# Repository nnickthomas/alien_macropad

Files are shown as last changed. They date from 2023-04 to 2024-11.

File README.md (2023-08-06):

# 👽Alien Macropad

A DIY standalone macropad using the Raspberry Pi Pico W for homeassistant, twitch, or anything.

  

👽 🐄 🛸 ⭐ 🌙 🪐 🌌

them big green aliens they came them gone they took my cows

## Features 🐄

- Designed for the Pi Pico W
- Standalone device, not a keypad
- Open Source PCB designs (all files required to print your own PCB)
- Fits cherry-style switches (either plate or pcb mount)

## GPIO Pinout Map 🛸

The following pins on the Pi's GPIO pinouts correspond to the following switches:

| Switch  | GPIO Pin |
| --- | --- |
| SW1  | GP5 |
| SW2  | GP6  |
| SW3  | GP4  |
| SW4  | GP7  |
| SW5  | GP3  |
| SW6  | GP8 |

Please note that odd numbered switches (SW1, SW3, SW5) share a common ground and even numbered switches (SW2, SW4, SW6) share a common ground.
## Assembly ⭐

The alien macropad requires the following components:

| Component  | Amount |
| --- | --- |
| Cherry Style Switches | 6x |
| Raspberry Pi Pico W  | 1x  |
| Alien Macropad PCB  | 1x  |
| Top Sandwich Plate  | 1x  |
| Surrounding Case  | 1x |
| Adhesive Rubber Feet  | 4x |

The following steps detail how to assemble the device:

1) Place the PI into the U1 slot on the PCB and solder into place from the top. Please note that it may be easier for some people to perform the installation step at this phase as the Boostel button will be partially covered by the top sandwich!
2) Place the Top Sandwich Plate on top
3) Insert switches SW1-SW6 into the slots and solder into place from the bottom.
4) Place inside the Surrounding Case! (Alternatively use the Bottom Sandwich Plate for a lower profile look)
5) Proceed to Installation!

## Installation 🌙

This section will detail how to install the Alien Macropad software onto the now connected Pi Pico W. Please note this has not yet been tested! Also see the official [Raspberry Pi Documentation](https://projects.raspberrypi.org/en/projects/get-started-pico-w/)

   1) Download the latest version of the alien macropad. There will be two files inside (main.py and conf.json)
   2) Set your wi-fi credentials in conf.json. Create your actions in conf.json (see the [firmware documentation](https://github.com/nnickthomas/alien_macropad/tree/main/Firmware).
   3) Connect the microUSB cable to the Pi Pico W.
   4) While holding down the "Boostel" button on the PICO, connect the device to another computer.
   5) Copy the main.py file, and your modified conf.json onto the pi into the now opened directory. The file manager will open automatically on Windows and the files can be dragged over.
   6) Download the correct [firmware](https://rpf.io/pico-w-firmware) for the Pi Pico W. The regular Pi Pico has not been tested.
   7) Copy the firmware file above onto the opened directory.

    **_NOTE:_**  It is critical to add main.py and conf.json before the pico firmware!
    
## Configuration 🪐

The Alien Macropad uses a JSON file to configure functionality. The JSON file is also where the wi-fi credentials are set.

For instructions on how to configure the device, see the [firmware]((https://github.com/nnickthomas/alien_macropad/tree/main/Firmware)) section.

## Project Structure 🌌

    alien_macropad/
    ├── Case
    │   ├── PCB_Model.obj
    │   ├── alien_macro_lower_sandwich.stl
    │   └── alien_macro_top_sandwich.stl
    ├── Firmware
    │   ├── .picowgo
    │   ├── README.md
    │   ├── conf.json
    │   └── main.py
    ├── Gerber Files
    │   ├── Macropad-B_Cu.gbr
    │   ├── Macropad-B_Mask.gbr
    │   ├── Macropad-B_Paste.gbr
    │   ├── Macropad-Edge_Cuts.gbr
    │   ├── Macropad-F_Cu.gbr
    │   ├── Macropad-F_Mask.gbr
    │   ├── Macropad-F_Paste.gbr
    │   ├── Macropad-F_Silkscreen.gbr
    │   ├── Macropad-NPTH-drl_map.gbr
    │   ├── Macropad-NPTH.drl
    │   ├── Macropad-PTH-drl_map.gbr
    │   ├── Macropad-PTH.drl
    │   └── Macropad-job.gbrjob
    ├── .gitignore
    ├── LICENSE
    └── README.md

The main directory contains the following files and directories:

 - Case/: A directory containing the STL files for 3D printing the case.
 - Firmware/: A directory containing the firmware files for the Alien Macropad.
 - Gerber Files/: A directory containing the Gerber files for manufacturing the PCB.
 - .gitignore: The Git ignore file for the project.
 - LICENSE: The license file for the project.
 - README.md: The project's main README file.

The Case/ directory contains the following files:

 - PCB_Model.obj: An OBJ file with the PCB size for reference. Not used in assembly.
 - alien_macro_lower_sandwich.stl: An STL file for 3D printing the bottom part of the case.
 - alien_macro_top_sandwich.stl: An STL file for 3D printing the top part of the case.

The Firmware/ directory contains the following files:

 - .picowgo: This file is just used to identify a project folder.
 - README.md: A README file for the Firmware/ directory.
 - conf.json: A configuration file for the Alien Macropad.
 - main.py: The main firmware code for the Alien Macropad.

The Gerber Files/ directory contains the following files:

 - Macropad-B_Cu.gbr: The bottom copper layer of the PCB.
 - Macropad-B_Mask.gbr: The bottom solder mask layer of the PCB.
 - Macropad-B_Paste.gbr: The bottom paste layer of the PCB.
 - Macropad-Edge_Cuts.gbr: The edge cut layer of the PCB.
 - Macropad-F_Cu.gbr: The top copper layer of the PCB.
 - Macropad-F_Mask.gbr: The top solder mask layer of the PCB.
 - Macropad-F_Paste.gbr: The top paste layer of the PCB.
 - Macropad-F_Silkscreen.gbr: The top silkscreen layer of the PCB.
 - Macropad-NPTH.drl: The non-plated through holes drill file.
 - Macropad-PTH.drl: The plated through holes drill file.
 - Macropad-job.gbrjob: The job file for manufacturing the PCB.

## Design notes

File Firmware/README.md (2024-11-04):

# 👽 Alien Macropad Firmware

This directory contains the firmware for the Alien Macropad. The firmware is written in Circuitpython and is designed to run on the Pico microcontroller.

## GPIO Pinout Map 🛸

The following pins on the Pi's GPIO pinouts correspond to the following switches:

| Switch  | GPIO Pin |
| --- | --- |
| SW1  | GP5 |
| SW2  | GP6  |
| SW3  | GP4  |
| SW4  | GP7  |
| SW5  | GP3  |
| SW6  | GP8 |

Please note that odd numbered switches (SW1, SW3, SW5) share a common ground and even numbered switches (SW2, SW4, SW6) share a common ground.

## First Time Setup

To get started with the Alien Macropad, follow these steps:

1. Install the latest version of CircuitPython on the Pico. You can download the latest version of CircuitPython from the [CircuitPython website](https://circuitpython.org/board/raspberry_pi_pico_w/). (Note: The Alien Macropad firmware was developed using CircuitPython 9.0.4.)

2. Copy the contents of this directory to the Pico. You can do this by copying the contents of the `Firmware` directory to the `CIRCUITPY` drive on the Pico.

3. Once the files have been copied, reboot the Pico and hold down `SW1`. The Alien Macropad will boot into setup mode and create a Wi-Fi access point called `AlienPad`. Connect to this access point using your computer or mobile device.

4. Once connected to the `AlienPad` access point, open a web browser and navigate to `http://192.168.4.1`. You will be prompted to select the SSID and enter the password for your Wi-Fi network. Enter the SSID and password and click `Connect`.

5. (Optional) If you want to configure an MDNS name for the Alien Macropad, you can do so by entering the desired name in the `MDNS Name` field before clicking `Connect`.

6. Once you have connected to your Wi-Fi network, the Alien Macropad will reboot and connect to the network. You can now access the Alien Macropad by navigating to `http://<mdns_name>.local` or `http://<ip_address>` in your web browser. The default MDNS name is `alienpad.local`.

## ☄️ Configuration

The Alien Macropad buttons are configured via the web interface. Unless you have deviated from the provided gerber files, the default layout in the web interface should match the physical layout of the Alien Macropad.

### 🚀 Buttons

Each key can be configured to action something different. This supports multiple actions per key, and toggling funtionality.

The Alien Macropad firmware supports all types of HTTP requests:

For both types of requests, the following parameters can be configured:

 - url: The URL to send the request to
 - json: A JSON payload to include in the request
 - headers: A dictionary of headers to include in the request
 - data: The data to include in the request body

### 🌟 Sequence Mode

In sequence mode, each button press sends a sequence of requests to the configured URLs, in the order the requests are defined. Once all requests in the sequence have been sent, the button will no longer send any requests until it is pressed again.

To use sequence mode, set the "mode" value to "sequence", then add your requests underneath it.

### 🌓 Cycle Mode

In cycle mode, each button press sends a single request defined in under 'request' one at a time, waiting for a new button press before sending the next. Once it reaches the end it will loop back to the beginning.

To use cycle mode, set the "mode" value to "cycle", then add your requests underneath it.

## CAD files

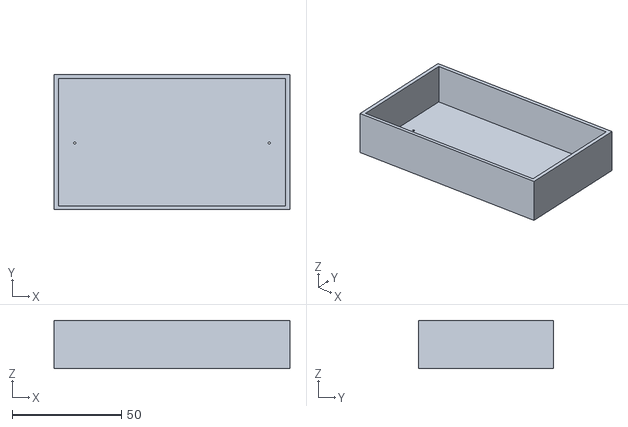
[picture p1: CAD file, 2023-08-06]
Case/alien_macro_surrounding_case.stl
108.0 x 62.0 x 22.0

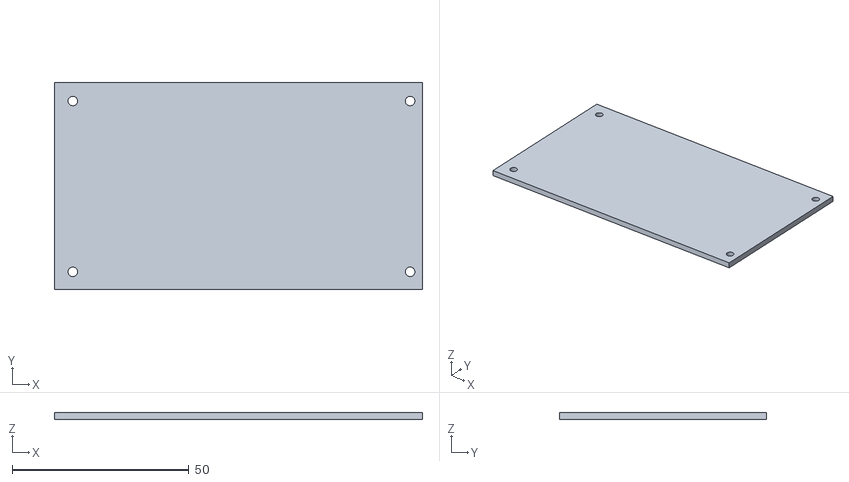
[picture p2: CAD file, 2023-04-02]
Case/alien_macro_lower_sandwich.stl
104.0 x 58.5 x 2.00

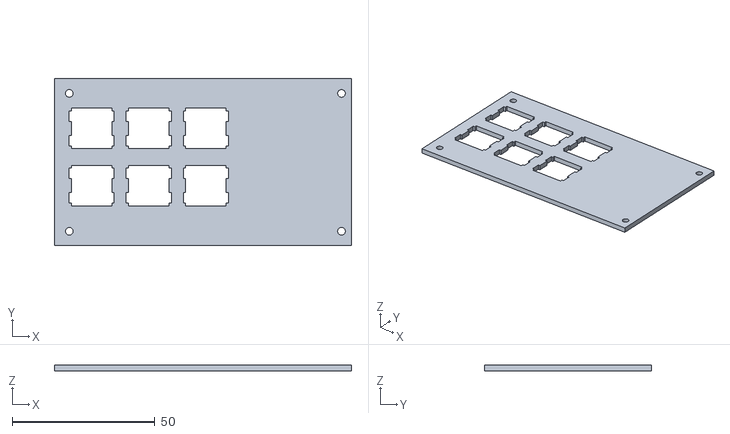
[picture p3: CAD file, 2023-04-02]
Case/alien_macro_top_sandwich.stl
104.0 x 58.5 x 2.00

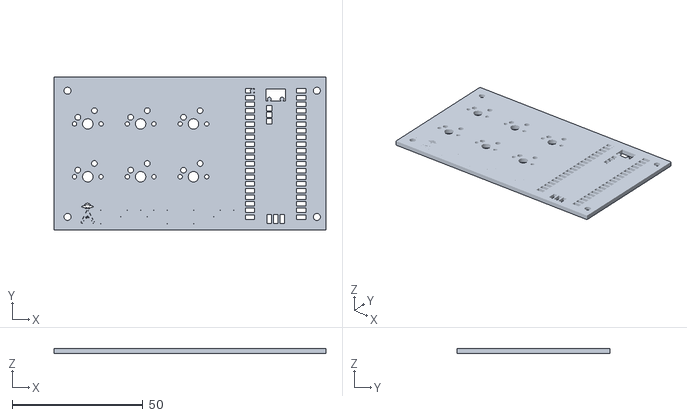
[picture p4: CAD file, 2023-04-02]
Case/PCB_Model.obj
104.0 x 58.5 x 2.00

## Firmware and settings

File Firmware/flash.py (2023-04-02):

import time
import json
import network
import uasyncio
import urequests

from machine import Pin

# Get configuration
with open("/conf.json") as fil:
    CONFIG = json.load(fil)

# On-board LED
LED = Pin("LED", Pin.OUT)

#------------------------------------------------
#                Task Functions
#------------------------------------------------
def blink_led(amt: int, speed: float) -> None:
    """Blinks the on-board LED

    Args:
        amt (int): Amount of times to blink the LED
        speed (float): Time in seconds to wait between blinks
    """
    for _ in range(amt * 2):
        LED.toggle()
        time.sleep(speed)


def connect_to_network(timeout: int = 10) -> bool:
    """Connect to the network defined in conf.py

    Args:
        timeout (int, optional): Amount of time in seconds to wait to connect. Defaults to 10.
    """
    wlan = network.WLAN(network.STA_IF)
    wlan.active(True)
    wlan.connect(CONFIG["network"]["ssid"], CONFIG["network"]["password"])

    # Wait for `timeout` seconds
    while timeout > 0:
        # If successful, blink the LED three times quickly and return True
        if wlan.status() < 0 or wlan.status() >= 3:
            blink_led(3, 0.1)
            LED.off()
            return True
        timeout -= 1
        blink_led(1, 1)

    # Deactivate network adapter and return False if failure to connect
    wlan.active(False)
    return False


#------------------------------------------------
#                Button Functions
#------------------------------------------------
async def switch_listener(button: dict, lock: uasyncio.Lock):
    """Asyncio function for listening to switch presses

    Args:
        button (dict): Button dict containing important information
        lock (uasyncio.Lock): Lock to ensure only one switch is pressed at a time
    """
    is_pressed = False
    switch = Pin(button["gpio"], Pin.IN, pull=Pin.PULL_UP)

    while True:
        # Handle button press
        if switch.value() == 0 and not is_pressed and not lock.locked():
            await lock.acquire()
            is_pressed = True

            res = urequests.request(**button["request"])

            if res:
                res.close()
            uasyncio.sleep_ms(200)

        # Release lock and set is_pressed to False
        if is_pressed and switch.value():
            is_pressed = False
            lock.release()

        await uasyncio.sleep_ms(5)


async def run_switch_listeners():
    """Main function to drive the Pico"""
    lock = uasyncio.Lock()
    for button in CONFIG["buttons"]:
        uasyncio.create_task(switch_listener(button, lock))


#------------------------------------------------
#                Main Function
#------------------------------------------------
def main():
    """Main Function"""
    if not connect_to_network():
        # If the board failed to connect to the network, blink a lot
        while True:
            blink_led(1, 0.1)
    
    uasyncio.run(run_switch_listeners())

    loop = uasyncio.get_event_loop()
    loop.run_forever()


if __name__ == "__main__":
    main()

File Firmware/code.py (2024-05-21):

import os
import json
import supervisor

from setup import setup_mode
from handler import running_mode

supervisor.set_next_code_file(filename = 'code.py', reload_on_error = False, reload_on_success = False)
supervisor.runtime.autoreload = False

if __name__ == '__main__':
    if os.getenv('MODE') == 'setup':
        setup_mode()
    else:
        try:
            with open('/wifi.json') as fil:
                wifi_config = json.load(fil)
                running_mode(**wifi_config)
        except Exception as e:
            setup_mode()

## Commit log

2023-04-02 Initial commit with hardware relevant files
    This includes the gerber files and the super simple sandwich case for the alien macropad.
    [Macropad-B_Cu.gbr, Macropad-B_Mask.gbr, Macropad-B_Paste.gbr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]
2023-04-02 Changed switch to button
2023-04-02 Added button types sequence and cycle
2023-08-06 Lower Case Redesign
    Changing bottom case design because who likes sandwiches anyway?
    [alien_macro_surrounding_case.stl]
2023-08-06 Update README.md to reflect Surrounding Case design
    Updating Assembly Guide to reflect updates. Who likes a sandwich anyways?
